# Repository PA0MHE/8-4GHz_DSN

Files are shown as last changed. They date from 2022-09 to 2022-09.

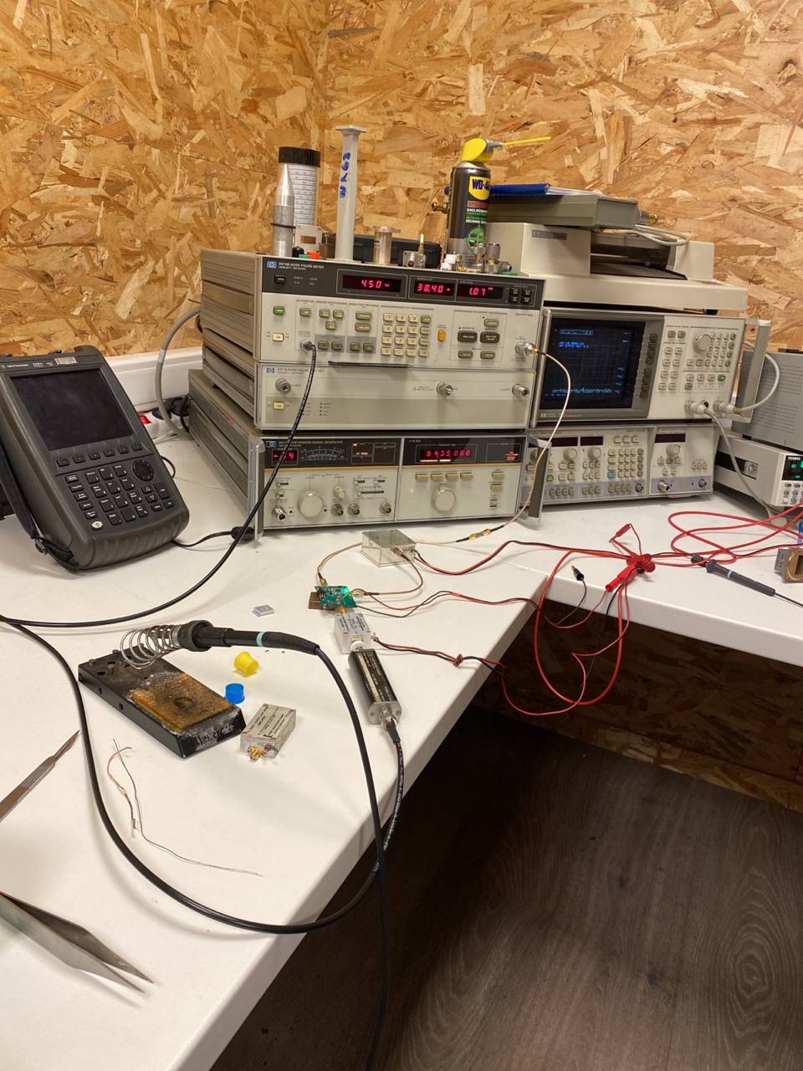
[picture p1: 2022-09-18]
Kenny_I.jpg

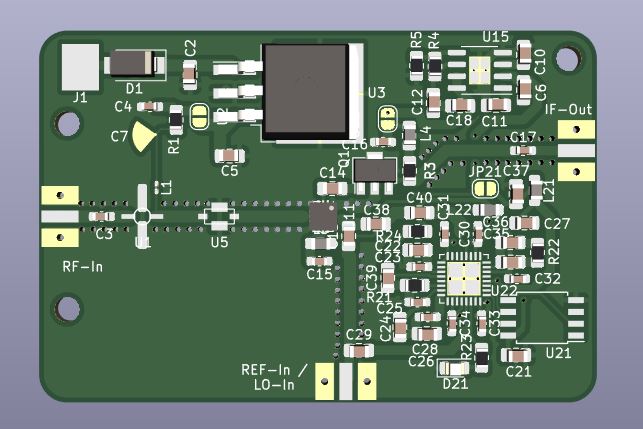
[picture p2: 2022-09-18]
8-4GHz_DSN_Top.JPG

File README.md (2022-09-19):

# 8-4GHz_DSN

8.4 GHz DSN downconverter, intended to use with external LNA (e.g. 25dB Gain, 1dB NF) in front  
Input : 8400 .. 8470 MHz  
Output: 400 .. 470 MHz  
REF-in: 10 MHz  0.7-3.3 Vpp reference input from an OCXO or GPSDO   
Supply: 8V DC  
The converter itself has a conversion gain of around 13dB  

# Key components:

MGA-86576  
BFCN-8450+  
LTC5549  
ADF4351  
ADM7150/1  
ATtiny85-20S  

# PCB

Gerber files are included, PCB's can be ordered at JCL PCB substrate thickness is 0.6mm 

73's Maarten PA0MHE

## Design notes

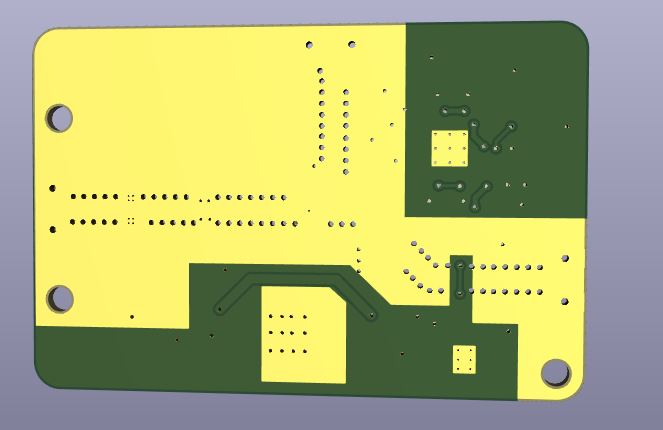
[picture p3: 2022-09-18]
8-4GHz_DSN_Bottom.JPG

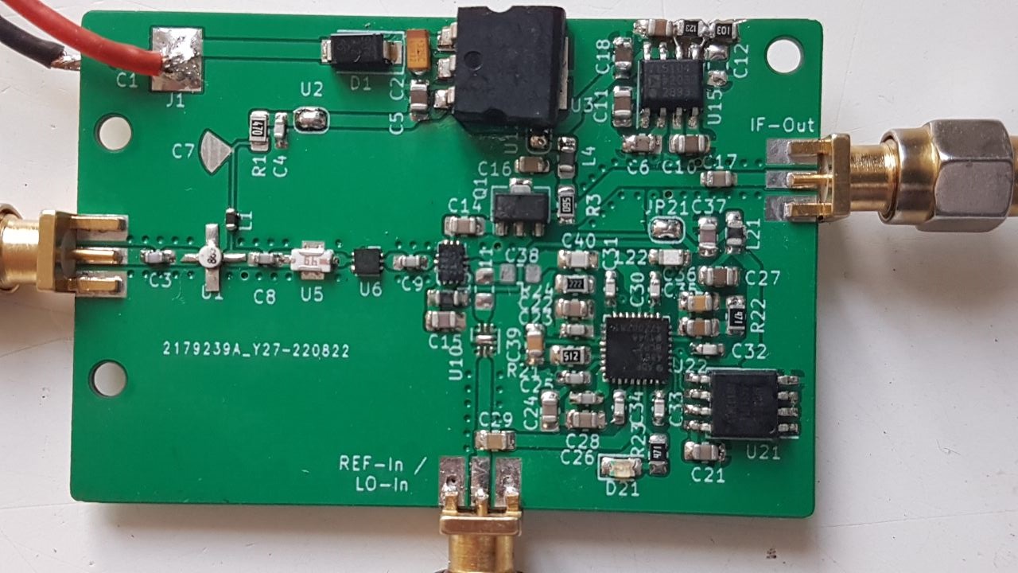
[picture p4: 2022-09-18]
DSN.jpg

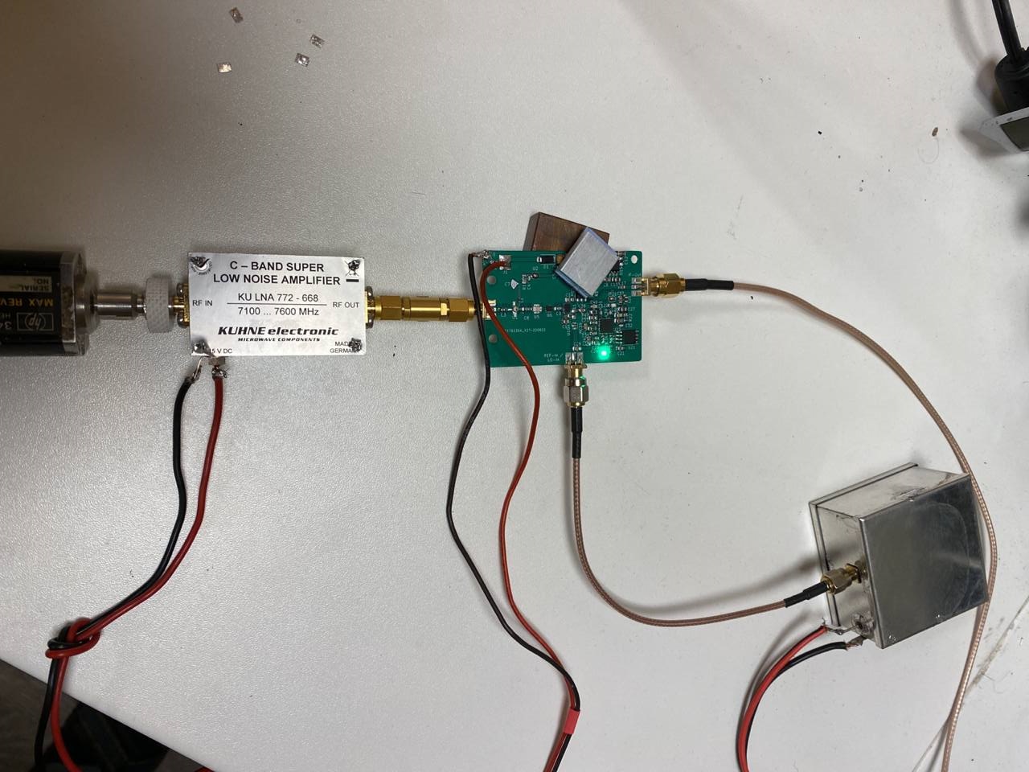
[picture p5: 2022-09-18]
Kenny_II.jpg

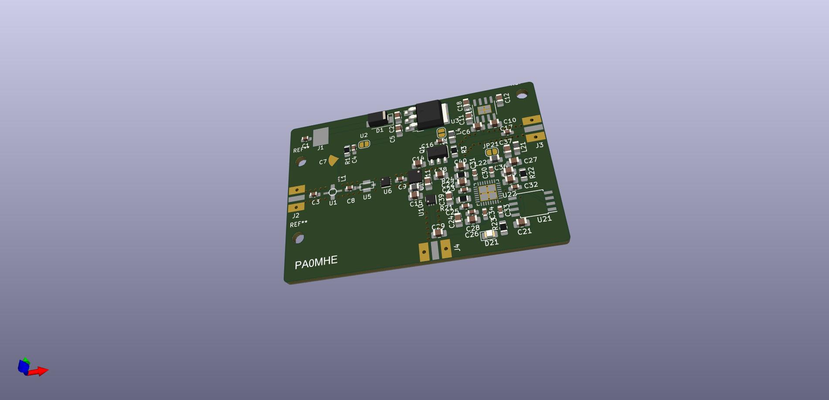
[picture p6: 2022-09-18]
Kicad6/8-4GHzDSN_V2.jpg

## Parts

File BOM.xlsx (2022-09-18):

Reference | Quantity | Value | Footprint | Datasheet
C10 C12 | 2 | 1u | Capacitor_SMD:C_0805_2012Metric_Pad1.18x1.45mm_HandSolder
C13 | 1 | 5p6 | Capacitor_SMD:C_0805_2012Metric_Pad1.18x1.45mm_HandSolder
C14 C37 | 2 | 100p | Capacitor_SMD:C_0805_2012Metric_Pad1.18x1.45mm_HandSolder
C18 C21 C22 C24 C26 | 5 | 100n | Capacitor_SMD:C_0805_2012Metric_Pad1.18x1.45mm_HandSolder
C2 C5 C6 C11 C27 | 5 | 10u | Capacitor_SMD:C_0805_2012Metric_Pad1.18x1.45mm_HandSolder
C23 C25 C28 | 3 | 10p | Capacitor_SMD:C_0603_1608Metric_Pad1.08x0.95mm_HandSolder
C29 | 1 | 1n | Capacitor_SMD:C_0805_2012Metric_Pad1.18x1.45mm_HandSolder
C3 | 1 | 2p | Capacitor_SMD:C_0603_1608Metric_Pad1.08x0.95mm_HandSolder
C35 | 1 | 47n | Capacitor_SMD:C_0805_2012Metric_Pad1.18x1.45mm_HandSolder
C36 | 1 | 3n3 | Capacitor_SMD:C_0805_2012Metric_Pad1.18x1.45mm_HandSolder
C38 C40 | 2 | 6p8 | Capacitor_SMD:C_0805_2012Metric_Pad1.18x1.45mm_HandSolder
C39 | 1 | 470p | Capacitor_SMD:C_0805_2012Metric_Pad1.18x1.45mm_HandSolder
C4 C15 C16 C17 C30 C31 C32 C33 C34 | 9 | 100p | Capacitor_SMD:C_0603_1608Metric_Pad1.08x0.95mm_HandSolder
C7 | 1 | printedC | Maarten_Kicad6:PrintedC
D1 | 1 | SS34 | Diode_SMD:D_SMA
D21 | 1 | LED | LED_SMD:LED_0805_2012Metric_Pad1.15x1.40mm_HandSolder
J1 | 1 | +12V | Maarten_Kicad6:SolderWirePad_single_SMD_4x5mm
J2 | 1 | RF-In | Maarten_Kicad6:SMA_side_PCB
J3 | 1 | RF out | Maarten_Kicad6:SMA_side_PCB
J4 | 1 | LO-In | Maarten_Kicad6:SMA_side_PCB
JP21 | 1 | ~ | Jumper:SolderJumper-2_P1.3mm_Open_RoundedPad1.0x1.5mm
L1 | 1 | BLM18GG471SN1D | Inductor_SMD:L_0201_0603Metric_Pad0.64x0.40mm_HandSolder
L21 | 1 | 100u | Inductor_SMD:L_0805_2012Metric_Pad1.05x1.20mm_HandSolder
L22 | 1 | 3n9 | Inductor_SMD:L_0805_2012Metric_Pad1.05x1.20mm_HandSolder
L3 | 1 | 10n | Inductor_SMD:L_0805_2012Metric_Pad1.05x1.20mm_HandSolder
L4 | 1 | 150n | Inductor_SMD:L_0805_2012Metric_Pad1.15x1.40mm_HandSolder
Q1 | 1 | PGA103+ | Package_TO_SOT_SMD:SOT-89-3
R1 | 1 | 100R | Resistor_SMD:R_0805_2012Metric_Pad1.20x1.40mm_HandSolder
R21 | 1 | 5K1 | Resistor_SMD:R_0805_2012Metric_Pad1.20x1.40mm_HandSolder
R22 R23 | 2 | 470R | Resistor_SMD:R_0805_2012Metric_Pad1.20x1.40mm_HandSolder
R24 | 1 | 2K2 | Resistor_SMD:R_0805_2012Metric_Pad1.20x1.40mm_HandSolder
R3 | 1 | 56R | Resistor_SMD:R_0805_2012Metric_Pad1.20x1.40mm_HandSolder
R4 | 1 | 12K | Resistor_SMD:R_0805_2012Metric_Pad1.20x1.40mm_HandSolder
R5 | 1 | 10K | Resistor_SMD:R_0805_2012Metric_Pad1.20x1.40mm_HandSolder
U1 | 1 | MGA-86576 | Maarten_Kicad6:MGA-86576
U11 | 1 | LTC5549 | Maarten_Kicad6:QFN-12-UDB Var A 3.5x2.5mm
U15 | 1 | ADM7150 | Package_SO:SOIC-8-1EP_3.9x4.9mm_P1.27mm_EP2.29x3mm_ThermalVias
U2 U12 | 2 | SO | Jumper:SolderJumper-2_P1.3mm_Open_RoundedPad1.0x1.5mm
U21 | 1 | ATtiny85-20S | Package_SO:SOIC-8W_5.3x5.3mm_P1.27mm | http://ww1.microchip.com/downloads/en/DeviceDoc/atmel-2586-avr-8-bit-microcontroller-attiny25-attiny45-attiny85_datasheet.pdf
U22 | 1 | ADF4351 | Package_CSP:LFCSP-32-1EP_5x5mm_P0.5mm_EP3.6x3.6mm_ThermalVias | https://www.analog.com/media/en/technical-documentation/data-sheets/ADF4351.pdf
U3 | 1 | L7805 | Package_TO_SOT_SMD:TO-263-3_TabPin2 | http://www.st.com/content/ccc/resource/technical/document/datasheet/41/4f/b3/b0/12/d4/47/88/CD00000444.pdf/files/CD00000444.pdf/jcr:content/translations/en.CD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
U5 | 1 | BFCN-8450+ | Maarten_Kicad6:BFCN-8450

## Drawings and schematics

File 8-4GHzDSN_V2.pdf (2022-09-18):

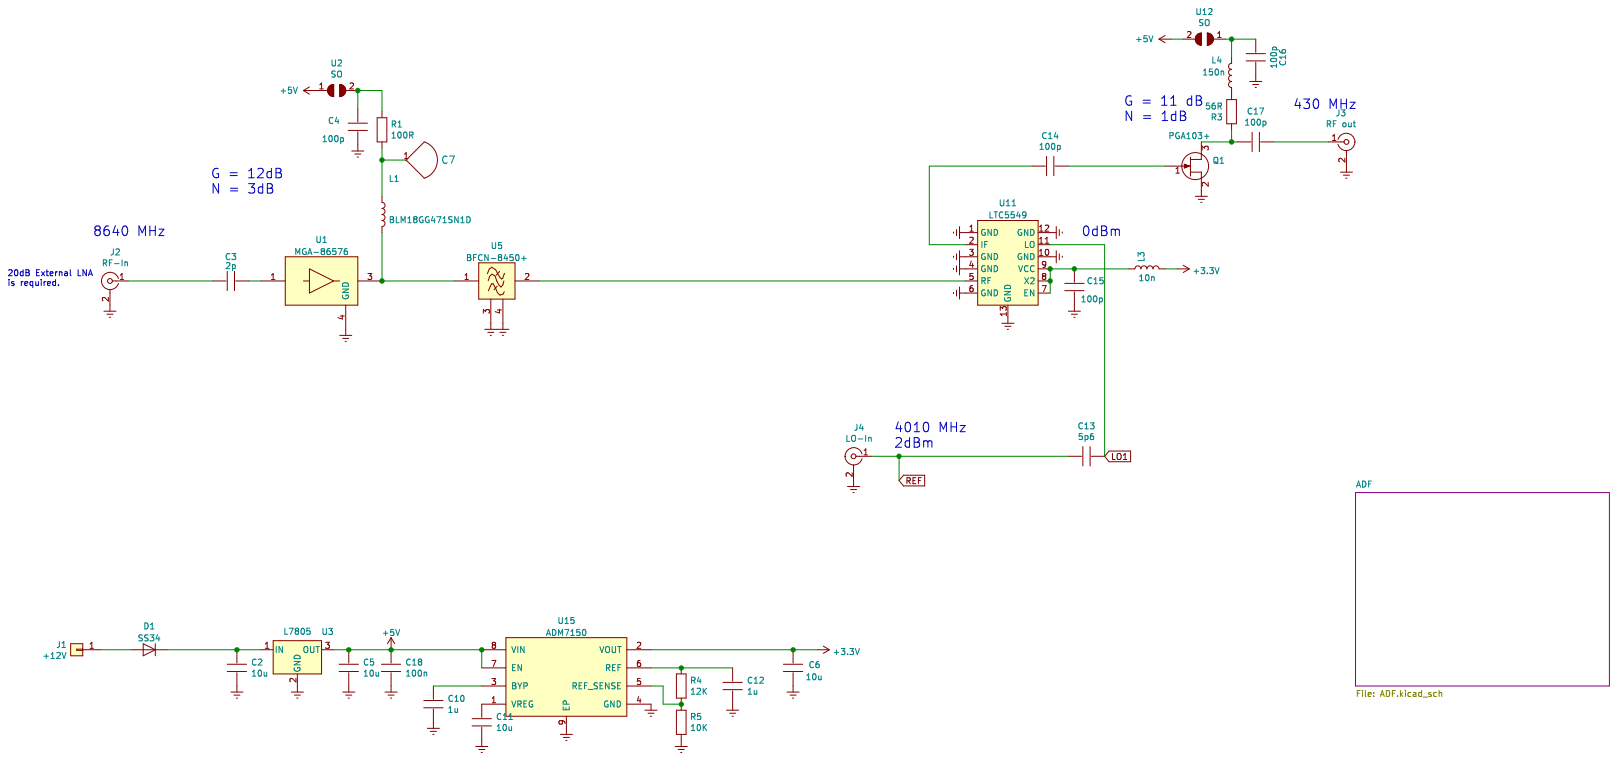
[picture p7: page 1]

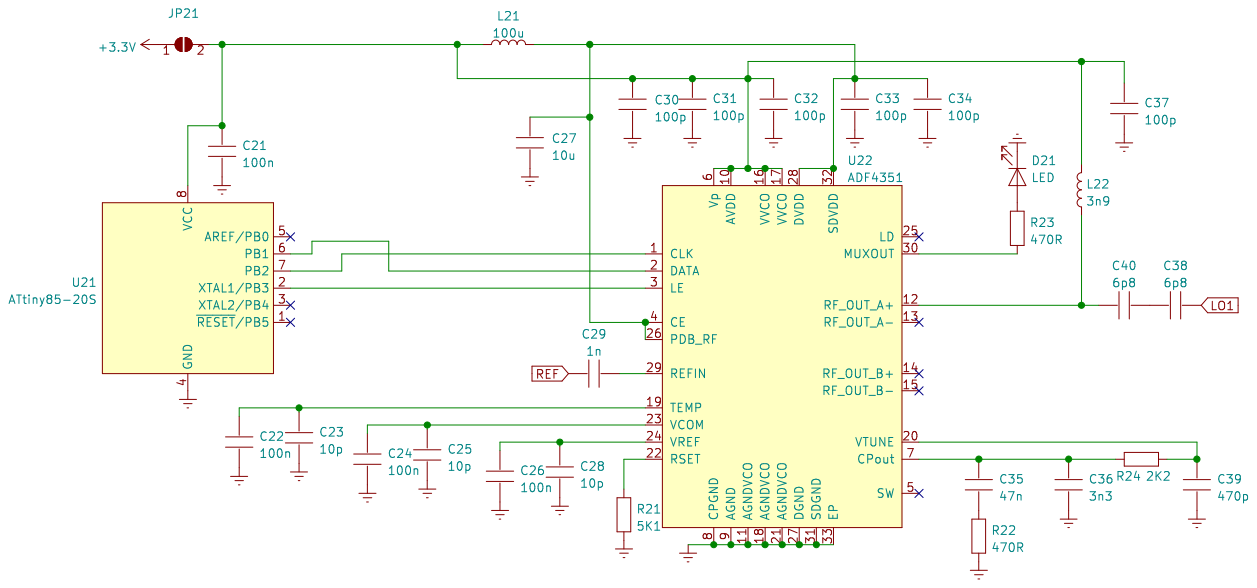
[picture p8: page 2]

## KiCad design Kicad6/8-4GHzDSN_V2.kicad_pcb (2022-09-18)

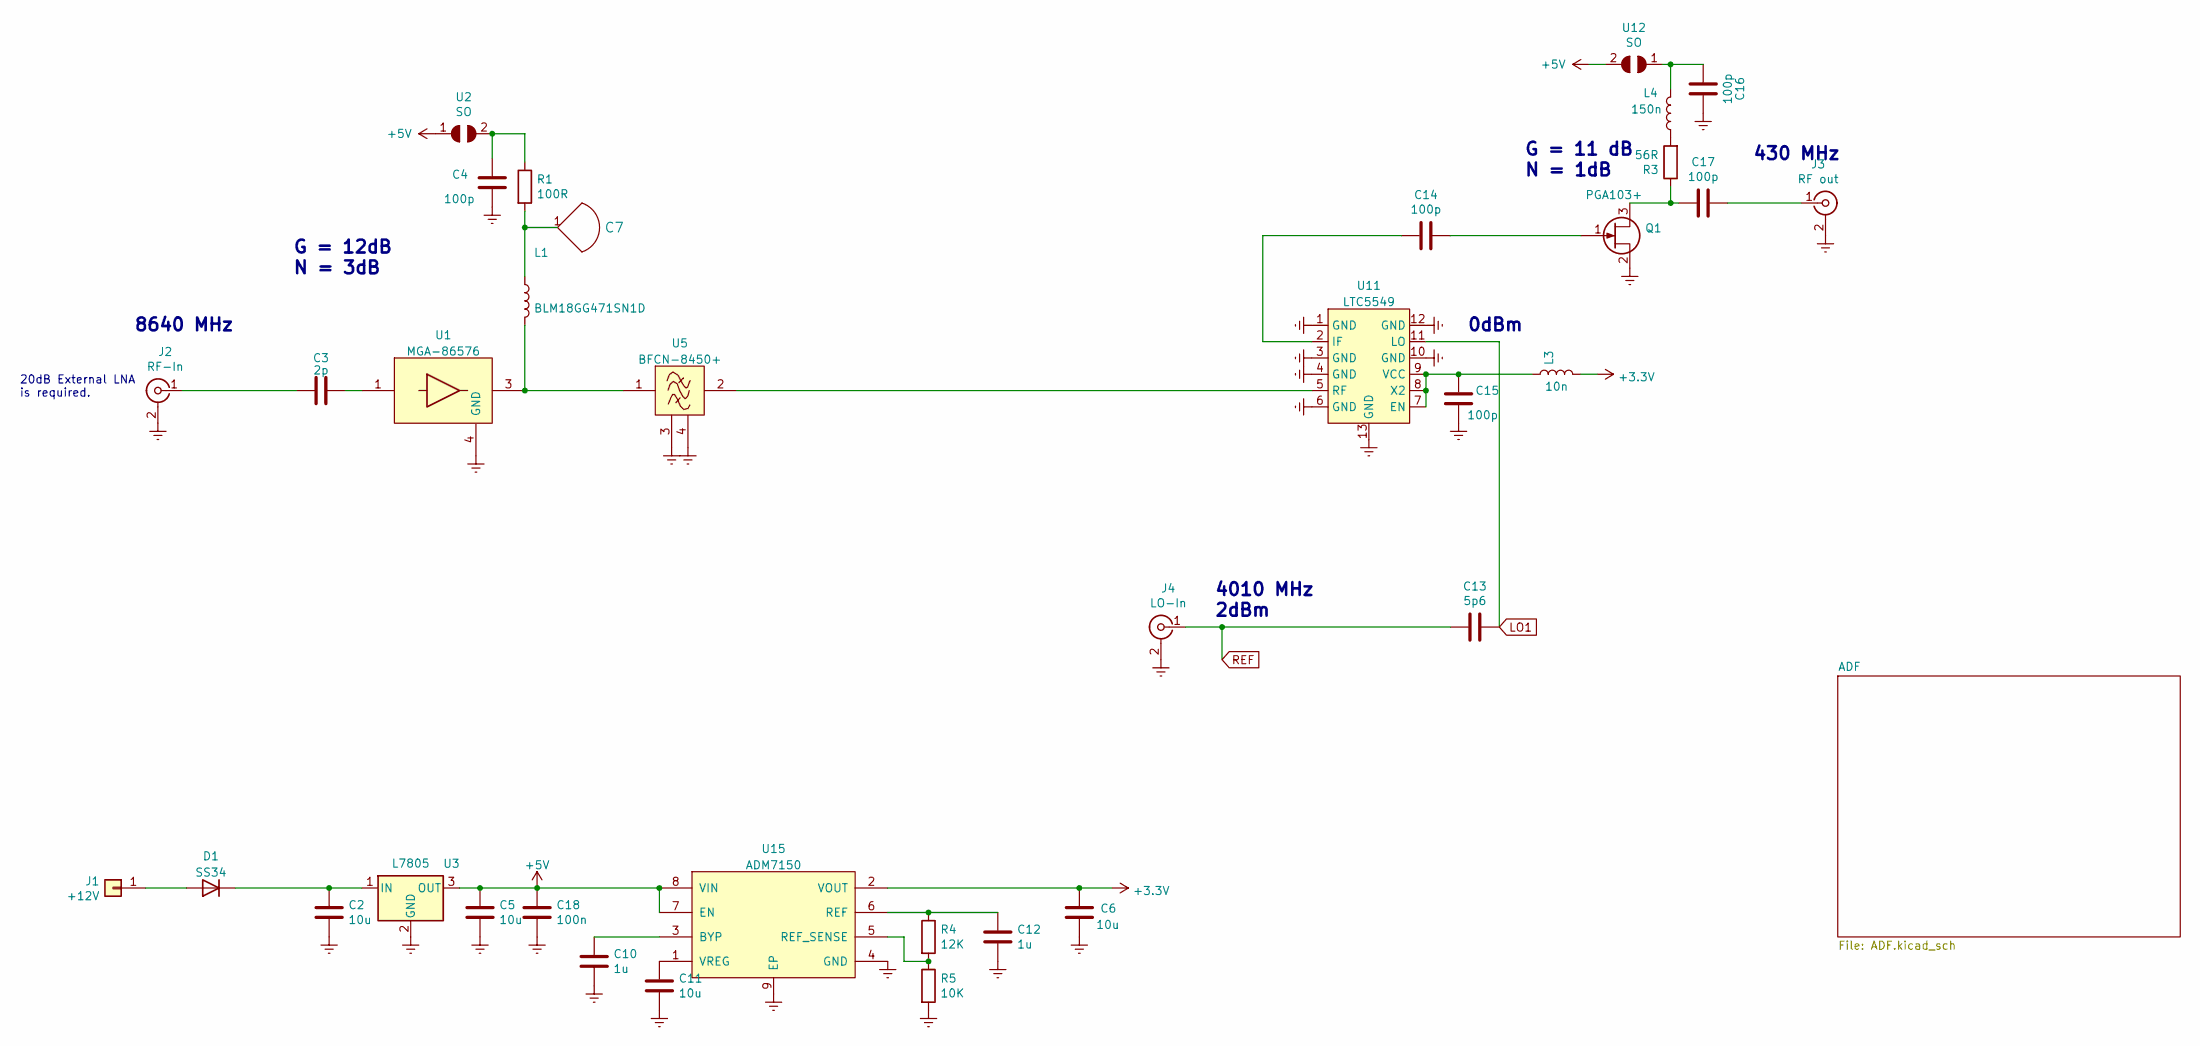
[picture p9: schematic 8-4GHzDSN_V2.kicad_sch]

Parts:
C2, C5, C6, C11: 10u; C_0805_2012Metric_Pad1.18x1.45mm_HandSolder
C3: 2p; C_0603_1608Metric_Pad1.08x0.95mm_HandSolder
C4, C15, C16, C17: 100p; C_0603_1608Metric_Pad1.08x0.95mm_HandSolder
C7: printedC; PrintedC
C10, C12: 1u; C_0805_2012Metric_Pad1.18x1.45mm_HandSolder
C13: 5p6; C_0805_2012Metric_Pad1.18x1.45mm_HandSolder
C14: 100p; C_0805_2012Metric_Pad1.18x1.45mm_HandSolder
C18: 100n; C_0805_2012Metric_Pad1.18x1.45mm_HandSolder
D1: SS34; D_SMA
J1: +12V; SolderWirePad_single_SMD_4x5mm
J2: RF-In; SMA_side_PCB
J3: RF out; SMA_side_PCB
J4: LO-In; SMA_side_PCB
L1: BLM18GG471SN1D; L_0201_0603Metric_Pad0.64x0.40mm_HandSolder
L3: 10n; L_0805_2012Metric_Pad1.05x1.20mm_HandSolder
L4: 150n; L_0805_2012Metric_Pad1.15x1.40mm_HandSolder
Q1: PGA103+; SOT-89-3
R1: 100R; R_0805_2012Metric_Pad1.20x1.40mm_HandSolder
R3: 56R; R_0805_2012Metric_Pad1.20x1.40mm_HandSolder
R4: 12K; R_0805_2012Metric_Pad1.20x1.40mm_HandSolder
R5: 10K; R_0805_2012Metric_Pad1.20x1.40mm_HandSolder
U1: MGA-86576
U2, U12: SO; SolderJumper-2_P1.3mm_Open_RoundedPad1.0x1.5mm
U3: L7805; TO-263-3_TabPin2
U5: BFCN-8450+; BFCN-8450
U11: LTC5549; QFN-12-UDB Var A 3.5x2.5mm
U15: ADM7150; SOIC-8-1EP_3.9x4.9mm_P1.27mm_EP2.29x3mm_ThermalVias

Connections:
+3V3: C6.2, L3.2, U15.2 (VOUT); also elsewhere on the board
+5V: C5.2, C18.2, U2.1, U3.3 (OUT), U12.2, U15.7 (EN), U15.8 (VIN)
GNDREF: C2.1, C4.1, C5.1, C6.1, C10.1, C11.1, C12.1, C15.1, C16.1, C18.1, J2.2 (Ext), J3.2 (Ext), J4.2 (Ext), Q1.2 (S), R5.2, U1.2 (GND), U1.4 (GND), U3.2 (GND), U5.3, U5.4, U11.1 (GND), U11.3 (GND), U11.4 (GND), U11.6 (GND), U11.10 (GND), U11.12 (GND), U11.13 (GND), U15.4 (GND), U15.9 (EP); also elsewhere on the board
LO1: C13.2, U11.11 (LO); also elsewhere on the board
unnamed: C2.2, D1.1 (K), U3.1 (IN)
unnamed: C3.1, J2.1 (In)
unnamed: C3.2, U1.1
unnamed: C4.2, R1.1, U2.2
unnamed: C7.1, L1.1, R1.2
unnamed: C10.2, U15.3 (BYP)
unnamed: C11.2, U15.1 (VREG)
unnamed: C12.2, R4.1, U15.6 (REF)
unnamed: C14.1, U11.2 (IF)
unnamed: C14.2, Q1.1 (G)
unnamed: C15.2, L3.1, U11.7 (EN), U11.8 (X2), U11.9 (VCC)
unnamed: C16.2, L4.1, U12.1
unnamed: C17.1, Q1.3 (D), R3.1
unnamed: C17.2, J3.1 (In)
unnamed: D1.2 (A), J1.1
unnamed: L1.2, U1.3, U5.1
unnamed: L4.2, R3.2
unnamed: R4.2, R5.1, U15.5 (REF_SENSE)
unnamed: U5.2, U11.5 (RF)
REF: C13.1, J4.1 (In); also elsewhere on the board

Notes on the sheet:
20dB External LNA is required.
8640 MHz
0dBm
4010 MHz 2dBm
G = 11 dB N = 1dB
G = 12dB N = 3dB
430 MHz

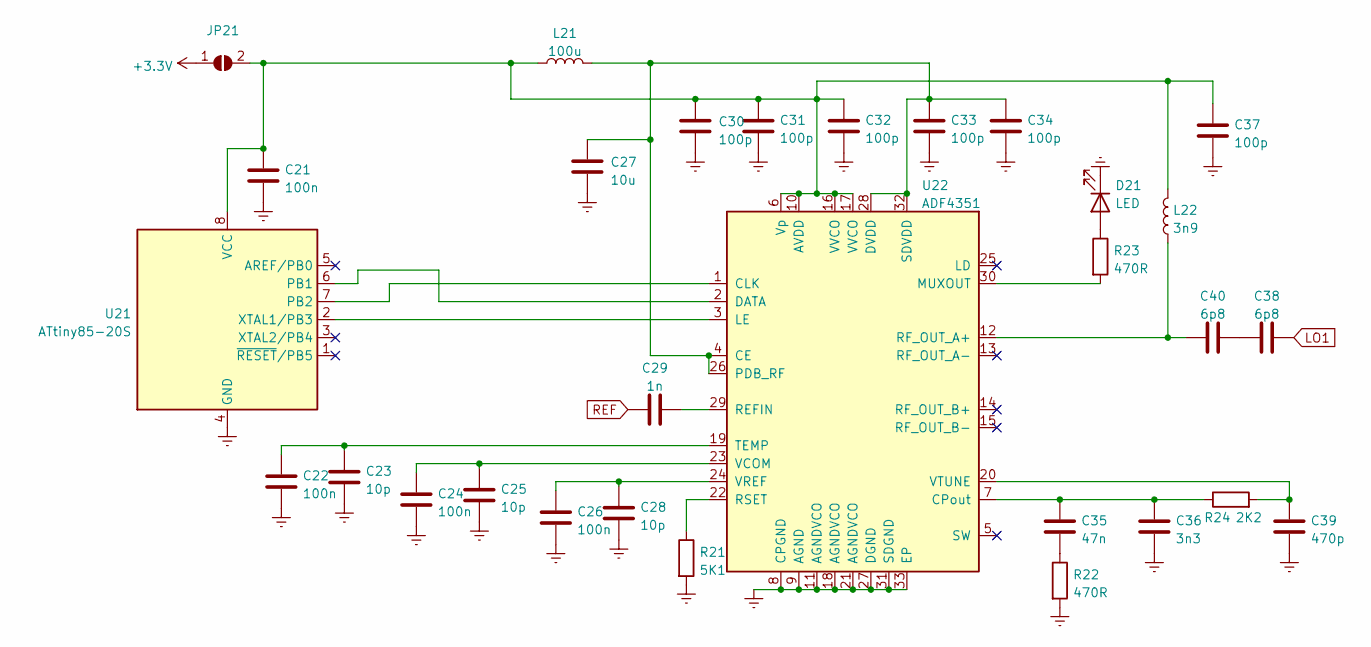
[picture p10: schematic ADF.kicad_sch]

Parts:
C21, C22, C24, C26: 100n; C_0805_2012Metric_Pad1.18x1.45mm_HandSolder
C23, C25, C28: 10p; C_0603_1608Metric_Pad1.08x0.95mm_HandSolder
C27: 10u; C_0805_2012Metric_Pad1.18x1.45mm_HandSolder
C29: 1n; C_0805_2012Metric_Pad1.18x1.45mm_HandSolder
C30, C31, C32, C33, C34: 100p; C_0603_1608Metric_Pad1.08x0.95mm_HandSolder
C35: 47n; C_0805_2012Metric_Pad1.18x1.45mm_HandSolder
C36: 3n3; C_0805_2012Metric_Pad1.18x1.45mm_HandSolder
C37: 100p; C_0805_2012Metric_Pad1.18x1.45mm_HandSolder
C38, C40: 6p8; C_0805_2012Metric_Pad1.18x1.45mm_HandSolder
C39: 470p; C_0805_2012Metric_Pad1.18x1.45mm_HandSolder
D21: LED; LED_0805_2012Metric_Pad1.15x1.40mm_HandSolder
JP21: SolderJumper-2_P1.3mm_Open_RoundedPad1.0x1.5mm
L21: 100u; L_0805_2012Metric_Pad1.05x1.20mm_HandSolder
L22: 3n9; L_0805_2012Metric_Pad1.05x1.20mm_HandSolder
R21: 5K1; R_0805_2012Metric_Pad1.20x1.40mm_HandSolder
R22, R23: 470R; R_0805_2012Metric_Pad1.20x1.40mm_HandSolder
R24: 2K2; R_0805_2012Metric_Pad1.20x1.40mm_HandSolder
U21: ATtiny85-20S; SOIC-8W_5.3x5.3mm_P1.27mm
U22: ADF4351; LFCSP-32-1EP_5x5mm_P0.5mm_EP3.6x3.6mm_ThermalVias

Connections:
+3V3: JP21.1 (A); also elsewhere on the board
GNDREF: C21.2, C22.2, C23.2, C24.2, C25.2, C26.2, C27.2, C28.2, C30.2, C31.2, C32.2, C33.2, C34.2, C36.2, C37.2, C39.2, D21.1 (K), R21.2, R22.2, U21.4 (GND), U22.8 (CPGND), U22.9 (AGND), U22.11 (AGNDVCO), U22.18 (AGNDVCO), U22.21 (AGNDVCO), U22.27 (DGND), U22.31 (SDGND), U22.33 (EP); also elsewhere on the board
LO1: C38.2; also elsewhere on the board
unnamed: C21.1, C30.1, C31.1, C32.1, C37.1, JP21.2 (B), L21.1, L22.2, U21.8 (VCC), U22.6 (Vp), U22.10 (AVDD), U22.16 (VVCO), U22.17 (VVCO)
unnamed: C22.1, C23.1, U22.19 (TEMP)
unnamed: C24.1, C25.1, U22.23 (VCOM)
unnamed: C26.1, C28.1, U22.24 (VREF)
unnamed: C27.1, C33.1, C34.1, L21.2, U22.4 (CE), U22.26 (PDB_RF), U22.28 (DVDD), U22.32 (SDVDD)
unnamed: C29.2, U22.29 (REFIN)
unnamed: C35.1, C36.1, R24.1, U22.7 (CPout)
unnamed: C35.2, R22.1
unnamed: C38.1, C40.2
unnamed: C39.1, R24.2, U22.20 (VTUNE)
unnamed: C40.1, L22.1, U22.12 (RF_OUT_A+)
unnamed: D21.2 (A), R23.1
unnamed: R21.1, U22.22 (RSET)
unnamed: R23.2, U22.30 (MUXOUT)
unnamed: U21.2 (XTAL1/PB3), U22.3 (LE)
unnamed: U21.6 (PB1), U22.2 (DATA)
unnamed: U21.7 (PB2), U22.1 (CLK)
REF: C29.1; also elsewhere on the board

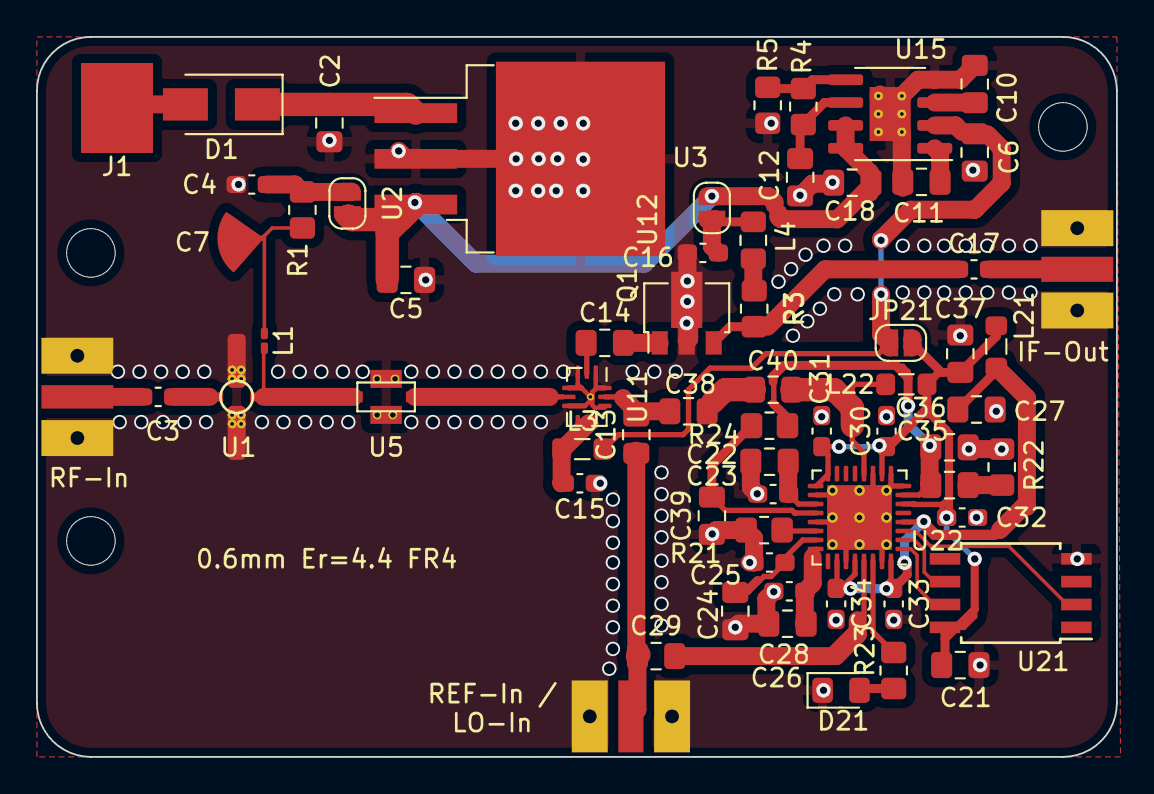
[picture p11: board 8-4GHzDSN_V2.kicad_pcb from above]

Board: 2 copper layers, 60.0 x 40.0 mm, 65 parts (0 on the bottom side), 41 nets.

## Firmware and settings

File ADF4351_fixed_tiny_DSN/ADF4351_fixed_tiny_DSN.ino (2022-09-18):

//  By Maarten PA0MHE 09-09-2022
//******************************************** HARDWARE ********************************************************
//  For ATTINY85 with DSN:
//  PB0   pin 5   
//  PB1   pin 6   ADF DAT
//  PB2   pin 7   ADF CLK
//  PB3   pin 2   ADF LE 
//  PB4   pin 3   
//  PB5   pin 1   
// 
//  Set the system clock to 1MHz internal.
//******************************************************************************************************************

#include <tinySPI.h>                     // https://github.com/JChristensen/tinySPI


#define ADF_LE DDB3                     // PIN2 storage register
#define CLK DDB2
#define DAT DDB1 

uint32_t registers[6] =  {0x640000, 0x8008011, 0x1A004E42, 0x4B3, 0x8A003C, 0x580005} ; // 4000 MHz with ref 10 MHz x2, 5dBm, MUXout digital lock detect

void setup() {
  SPI.begin();                           // Init SPI bus
  pinMode(ADF_LE, OUTPUT);               // latch pin needs to be set up
  digitalWrite(ADF_LE, HIGH);
 
  delay(1000);                            // Give ADF4351 time to setup

  ADFSet(registers, ADF_LE);

  }


void loop(){

} 


void ADFSet(uint32_t reg[6], byte LE) {  // Program all 6 registers ADF4351 
  for (int i = 5; i >= 0; i--) {         // program ADF4351 start with R5
    ADFWriteRegister32(reg[i], LE);
  } 
  delay(1);
  ADFWriteRegister32(reg[0], LE);        // Program R0 again
}


void ADFWriteRegister32(const uint32_t value, byte LE) //Program data into one of the 32bits register, the register that is selected by the four LSBs.
{
  digitalWrite(LE, LOW);
  for (int i = 3; i >= 0; i--)             // loop through 4 x 8bits
  SPI.transfer((value >> 8 * i) & 0xFF);   // shift , mask and send octet via SPI
  digitalWrite(LE, HIGH);                  // Load Enable rising edge the data stored in the shift register
  digitalWrite(LE, LOW);                   // 
}
